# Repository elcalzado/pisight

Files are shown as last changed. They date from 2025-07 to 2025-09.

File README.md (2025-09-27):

# PiSight

This is an adaptation of [Webcam Pi](https://www.github.com/elcalzado/webcampi) intended to be used alongside some components from the Apple iSight webcam. If you're interested in building this, follow this documentation and my YouTube video!

YouTube Video (https://www.youtube.com/watch?v=s-X41YuiVAM)

## Table of Contents

1. [Required Hardware](#required-hardware)
2. [Features](#features)
3. [Installation](#installation)
4. [Setup](#setup)
5. [Building](#building)
6. [Credits](#credits)

## Required Hardware

| Part | Description | Buy / Download |
| --- | --- | --- |
| Apple iSight | The shell for the camera | [eBay](https://www.ebay.com/sch/i.html?_nkw=apple+isight) |
| Raspberry Pi Zero 2 W | Main compute module | [Adafruit](https://www.adafruit.com/product/5291) |
| Camera Module 3 | CSI-2 camera module | [Adafruit](https://www.adafruit.com/product/5657) |
| microSD card (≥100 MB) | System storage | [Amazon](https://a.co/d/8l5QlQr) |
| USB-C cable | USB-OTG data & power | [Amazon](https://a.co/d/9c4WzDl) |
| USB-C female breakout board  | Replaces original micro‑USB port | [Amazon](https://a.co/d/h6eIS50) |
| Touchscreen breakout board | Shutter (IR sensor) adapter | [Adafruit](https://www.adafruit.com/product/334) |
| Resistors (5.6k, 150, 330) | Shutter sensor + activity/logo LEDs | [Amazon](https://a.co/d/awGgQPf) |
| Adafruit Sequin LED | Optional Apple logo back‑light | [Adafruit](https://www.adafruit.com/product/1758) |
| Any soldering iron | Wire soldering needed | [Amazon](https://www.amazon.com/s?k=soldering+iron) |
| Any drill with a 5/64 in bit | For swivel slot hole | [Amazon](https://www.amazon.com/s?k=drill) |
| 3D printed parts | Internal frame + mounting adapters  | [Printables](https://www.printables.com/model/1427221-pisight) |

## Features

PiSight keeps all the core functionality of Webcam Pi while adding hardware integration and quality‑of‑life features specific to the Apple iSight enclosure.

### Added / Changed vs Webcam Pi

- Apple iSight enclosure compatibility
- Lets you retain the original iSight’s tilt and axial twist
- Reused original activity LED
- Optional rear Apple logo illumination
- Integrated IR shutter / privacy sensor
	- For more info about how the sensor works check out: [isight-shutter](https://github.com/elcalzado/isight-shutter)
- USB‑C breakout replaces the original connector area
- Enumerates as a UVC device named “PiSight” (instead of “Webcam Pi”) with an updated manufacturer string

## Installation

1. Download the latest image from the [Releases](https://github.com/elcalzado/pisight/releases) page.
2. Insert your microSD card into your host computer.
3. Flash the image:
	- Linux/macOS:
   ```bash
   # Replace /dev/sdX with your card device
   sudo dd if=pisight-<version>.img of=/dev/sdX
   ```
	- Windows:
   ```
   Use a tool like Balena Etcher or Raspberry Pi Imager
   ```

## Setup

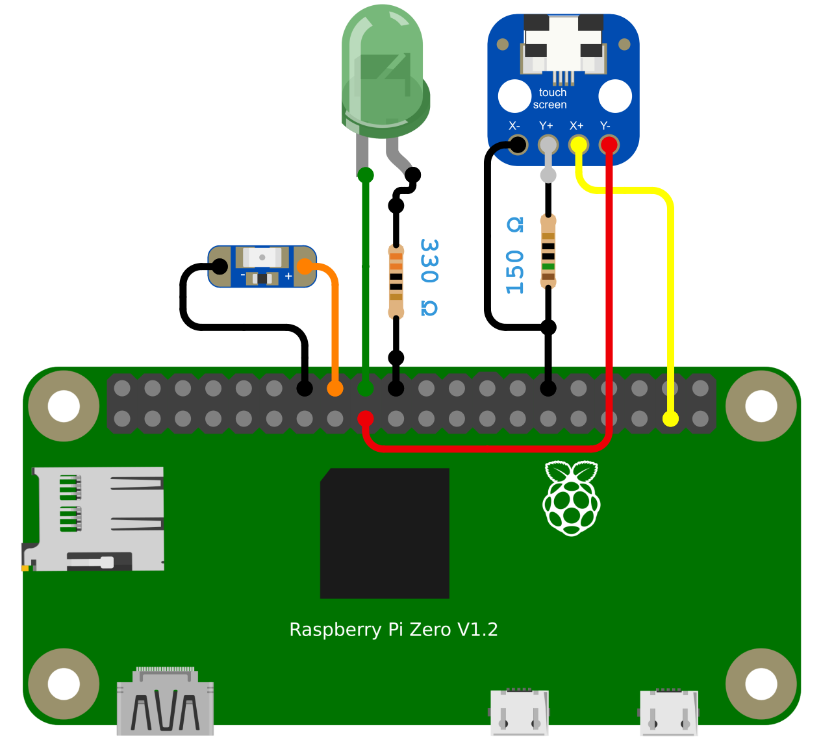
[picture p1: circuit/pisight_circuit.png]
Circuit Image


1. Insert the flashed microSD card into the Pi.
2. Assemble the camera (YouTube at the top video shows how I did it).
3. Plug an USB-C cable into the camera and the other end into your host USB port.
4. On your host machine, a new video device should appear.

## Building

### Prerequisites

- Linux host (WSL is fine)
- Git and buildroot dependencies

### Clone

```bash
git clone --recursive https://github.com/elcalzado/pisight.git
cd pisight
```

### Build

```bash
# This will configure Buildroot and compile the kernel, rootfs, and image
./build.sh
```

When complete, the final SD card image will be in:

```
buildroot/output/images/sdcard.img
```

Flash it as described in [Installation](#installation).

## Credits

- [webcampi](https://github.com/elcalzado/webcampi): The embedded linux image from which pisight is derived.
- [original pisight](https://github.com/maxbbraun/pisight): The project that inspired this!
- [isight-shutter](https://github.com/elcalzado/isight-shutter): Brief documentation for the Apple iSight's shutter sensor.

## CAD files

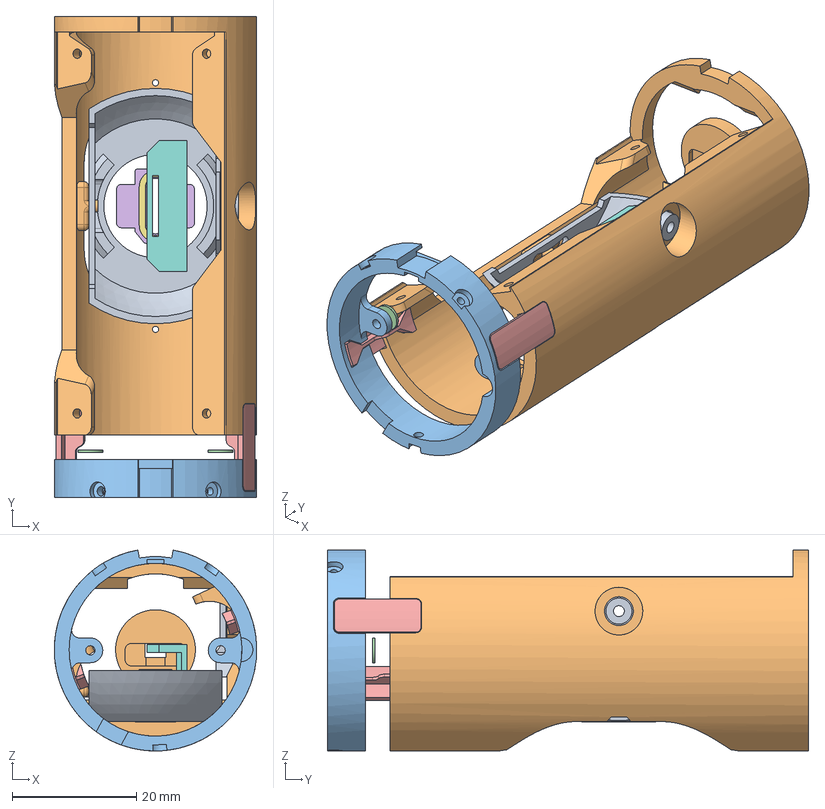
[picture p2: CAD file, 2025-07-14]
printing/pisight_innards.step
32.6 x 77.5 x 32.4 mm
iSight Swivel
Insert
Lens Adapter
Joints
USB-C Port

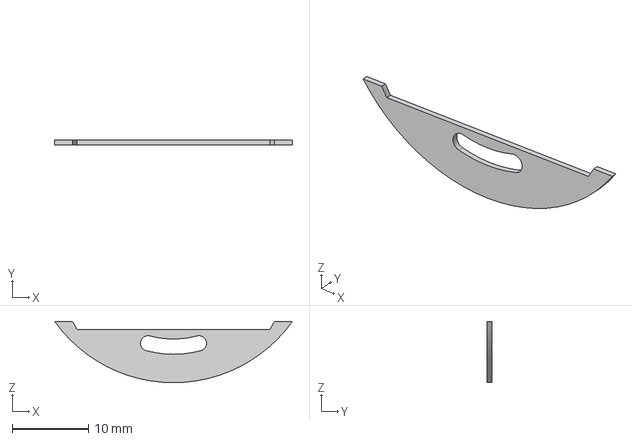
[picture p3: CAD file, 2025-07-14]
printing/swivel_stencil.step
31.3 x 0.6 x 8.06 mm

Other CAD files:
printing/pisight_innards.stl
printing/swivel_stencil.stl

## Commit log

2025-07-04 Configuration and build script
    - device-info.patch: change manuf and product strings for script
    - build.sh: apply patch and run webcampi's own build script
2025-07-14 Added 3D model files
    [pisight_innards.step, pisight_innards.stl, swivel_stencil.step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]
2025-09-26 Add circuit images for wiring
2025-09-26 Cut borders on circuit png
2025-09-27 Update Printables link for 3D printed parts
